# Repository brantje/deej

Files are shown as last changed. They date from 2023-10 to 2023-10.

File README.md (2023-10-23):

# deej

deej is an **open-source hardware volume mixer** for Windows and Linux PCs. It lets you use real-life sliders (like a DJ!) to **seamlessly control the volumes of different apps** (such as your music player, the game you're playing and your voice chat session) without having to stop what you're doing.

**Join the [deej Discord server](https://discord.gg/nf88NJu) if you need help or have any questions!**



> **_New:_** [work-in-progress deej FAQ](./docs/faq/faq.md)!

deej consists of a [lightweight desktop client](#features) written in Go, and an Arduino-based hardware setup that's simple and cheap to build. [**Check out some versions built by members of our community!**](./community.md)

**[Download the latest release](https://github.com/omriharel/deej/releases/latest) | [Video demonstration](https://youtu.be/VoByJ4USMr8) | [Build video by Tech Always](https://youtu.be/x2yXbFiiAeI)**

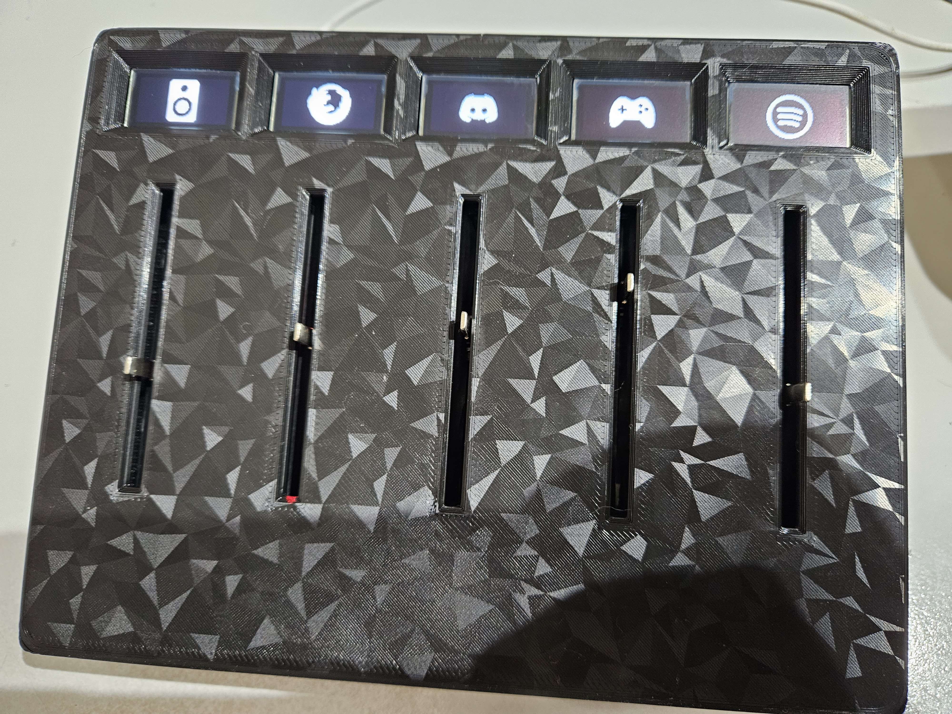
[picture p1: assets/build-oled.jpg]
deej


## BOM

- 1x Arduino Pro Micro
- 1x TCA9548A I2C Multiplexer
- 5x Sliding Potentiometer with Board (10kΩ) [example](assets/slider.jpg)
- 5x 0.96 inch OLED Display 128\*64 pixels (27mm x 27mm) (Cheap ones on eg AliExpress)

## Table of contents

- [Features](#features)
- [How it works](#how-it-works)
  - [Hardware](#hardware)
    - [Schematic](#schematic)
  - [Software](#software)
- [Slider mapping (configuration)](#slider-mapping-configuration)
- [Build your own!](#build-your-own)
  - [FAQ](#faq)
  - [Build video](#build-video)
  - [Bill of Materials](#bill-of-materials)
  - [Thingiverse collection](#thingiverse-collection)
  - [Build procedure](#build-procedure)
- [How to run](#how-to-run)
  - [Requirements](#requirements)
  - [Download and installation](#download-and-installation)
  - [Building from source](#building-from-source)
- [Community](#community)
- [License](#license)

## Features

deej is written in Go and [distributed](https://github.com/omriharel/deej/releases/latest) as a portable (no installer needed) executable.

- Bind apps to different sliders
  - Bind multiple apps per slider (i.e. one slider for all your games)
  - Bind the master channel
  - Bind "system sounds" (on Windows)
  - Bind specific audio devices by name (on Windows)
  - Bind currently active app (on Windows)
  - Bind all other unassigned apps
- Control your microphone's input level
- Lightweight desktop client, consuming around 10MB of memory
- Runs from your system tray
- Helpful notifications to let you know if something isn't working

> **Looking for the older Python version?** It's no longer maintained, but you can always find it in the [`legacy-python` branch](https://github.com/omriharel/deej/tree/legacy-python).

## How it works

### Hardware

- The sliders are connected to 5 (or as many as you like) analog pins on an Arduino Nano/Uno board. They're powered from the board's 5V output (see schematic)
- The board connects via a USB cable to the PC

#### Schematic

Hardware schematic

### Software

- The code running on the Arduino board is a [C program](./arduino/deej-5-sliders-vanilla/deej-5-sliders-vanilla.ino) constantly writing current slider values over its serial interface
- The PC runs a lightweight [Go client](./pkg/deej/cmd/main.go) in the background. This client reads the serial stream and adjusts app volumes according to the given configuration file

## Slider mapping (configuration)

deej uses a simple YAML-formatted configuration file named [`config.yaml`](./config.yaml), placed alongside the deej executable.

The config file determines which applications (and devices) are mapped to which sliders, and which parameters to use for the connection to the Arduino board, as well as other user preferences.

**This file auto-reloads when its contents are changed, so you can change application mappings on-the-fly without restarting deej.**

It looks like this:

```yaml
slider_mapping:
  0: master
  1: chrome.exe
  2: spotify.exe
  3:
    - pathofexile_x64.exe
    - rocketleague.exe
  4: discord.exe

# set this to true if you want the controls inverted (i.e. top is 0%, bottom is 100%)
invert_sliders: false

# settings for connecting to the arduino board
com_port: COM4
baud_rate: 9600

# adjust the amount of signal noise reduction depending on your hardware quality
# supported values are "low" (excellent hardware), "default" (regular hardware) or "high" (bad, noisy hardware)
noise_reduction: default
```

- `master` is a special option to control the master volume of the system _(uses the default playback device)_
- `mic` is a special option to control your microphone's input level _(uses the default recording device)_
- `deej.unmapped` is a special option to control all apps that aren't bound to any slider ("everything else")
- On Windows, `deej.current` is a special option to control whichever app is currently in focus
- On Windows, you can specify a device's full name, i.e. `Speakers (Realtek High Definition Audio)`, to bind that device's level to a slider. This doesn't conflict with the default `master` and `mic` options, and works for both input and output devices.
  - Be sure to use the full device name, as seen in the menu that comes up when left-clicking the speaker icon in the tray menu
- `system` is a special option on Windows to control the "System sounds" volume in the Windows mixer
- All names are case-**in**sensitive, meaning both `chrome.exe` and `CHROME.exe` will work
- You can create groups of process names (using a list) to either:
  - control more than one app with a single slider
  - choose whichever process in the group that's currently running (i.e. to have one slider control any game you're playing)

## Build your own!

Building deej is very simple. You only need a few relatively cheap parts - it's an excellent starter project (and my first Arduino project, personally). Remember that if you need any help or have a question that's not answered here, you can always [join the deej Discord server](https://discord.gg/nf88NJu).

Build deej for yourself, or as an awesome gift for your gaming buddies!

### FAQ

I've started a highly focused effort of writing a proper FAQ page for deej, covering many basic and advanced topics.

It is still _very much a work-in-progress_, but I'm happy to [share it in its current state](./docs/faq/faq.md) in hopes that it at least covers some questions you might have.

FAQ feedback in our [community Discord](https://discord.gg/nf88NJu) is strongly encouraged :)

### Build video

In case you prefer watching to reading, Charles from the [**Tech Always**](https://www.youtube.com/c/TechAlways) YouTube channel has made [**a fantastic video**](https://youtu.be/x2yXbFiiAeI) that covers the basics of building deej for yourself, including parts, costs, assembly and software. I highly recommend checking it out!

### Bill of Materials

- 1x Arduino Pro Micro
- 1x TCA9548A I2C Multiplexer
- 5x Sliding Potentiometer with Board (10kΩ) [example](assets/slider.jpg)
- 5x 0.96 inch OLED Display 128\*64 pixels (27mm x 27mm) (Cheap ones on eg AliExpress)

- An Arduino Nano, Pro Micro or Uno board
  - I officially recommend using a Nano or a Pro Micro for their smaller form-factor, friendlier USB connectors and more analog pins. Plus they're cheaper
  - You can also use any other development board that has a Serial over USB interface
- A few slider potentiometers, up to your number of free analog pins (the cheaper ones cost around 1-2 USD each, and come with a standard 10K Ohm variable resistor. These _should_ work just fine for this project)
  - **Important:** make sure to get **linear** sliders, not logarithmic ones! Check the product description
  - You can also use circular knobs if you like
- Some wires

That being said, if you do have one, read on...

### Thingiverse collection

With many different 3D-printed designs being added to our [community showcase](./community.md), it felt right to gather all of them in a Thingiverse collection for you to browse. If you have access to a 3D printer, feel free to use one of the designs in your build.

**[Visit our community-created design collection on Thingiverse!](https://thingiverse.com/omriharel/collections/deej)**

> You can also [submit your own](https://discord.gg/nf88NJu) design to be added to the collection. Regardless, if you do upload your design to Thingiverse, _please add a `deej` tag to it so that others can find it more easily_.

### Build procedure

- Connect everything according to the [schematic](#schematic)
- Test with a multimeter to be sure your sliders are hooked up correctly
- Flash the Arduino chip with the sketch in [`arduino\deej-5-sliders-vanilla`](./arduino/deej-5-sliders-vanilla/deej-5-sliders-vanilla.ino)
  - _Important:_ If you have more or less than 5 sliders, you must edit the sketch to match what you have
- After flashing, check the serial monitor. You should see a constant stream of values separated by a pipe (`|`) character, e.g. `0|240|1023|0|483`
  - When you move a slider, its corresponding value should move between 0 and 1023
- Congratulations, you're now ready to run the deej executable!

## How to run

### Requirements

#### Windows

- Windows. That's it

#### Linux

- Install `libgtk-3-dev`, `libappindicator3-dev` and `libwebkit2gtk-4.0-dev` for system tray support. Pre-built Linux binaries aren't currently released, so you'll need to [build from source](#building-from-source). If there's demand for pre-built binaries, please [let me know](https://discord.gg/nf88NJu)!

### Download and installation

- Head over to the [releases page](https://github.com/omriharel/deej/releases) and download the [latest version](https://github.com/omriharel/deej/releases/latest)'s executable and configuration file (`deej.exe` and `config.yaml`)
- Place them in the same directory anywhere on your machine
- (Optional, on Windows) Create a shortcut to `deej.exe` and copy it to `%APPDATA%\Microsoft\Windows\Start Menu\Programs\Startup` to have deej run on boot

### Building from source

If you'd rather not download a compiled executable, or want to extend deej or modify it to your needs, feel free to clone the repository and build it yourself. All you need is a Go 1.14 (or above) environment on your machine. If you go this route, make sure to check out the [developer scripts](./pkg/deej/scripts).

Like other Go packages, you can also use the `go get` tool: `go get -u github.com/omriharel/deej`. Please note that the package code now resides in the `pkg/deej` directory, and needs to be imported from there if used inside another project.

If you need any help with this, please [join our Discord server](https://discord.gg/nf88NJu).

## Community



deej is a relatively new project, but a vibrant and awesome community is rapidly growing around it. Come hang out with us in the [deej Discord server](https://discord.gg/nf88NJu), or check out a whole bunch of cool and creative builds made by our members in the [community showcase](./community.md).

The server is also a great place to ask questions, suggest features or report bugs (but of course, feel free to use GitHub if you prefer).

### Donations

If you love deej and want to show your support for this project, you can do so using the link below. Please don't feel obligated to donate - building the project and telling your friends about it goes a very long way! Thank you very much.



### Contributing

Please see [`docs/CONTRIBUTING.md`](./docs/CONTRIBUTING.md).

## License

deej is released under the [MIT license](./LICENSE).

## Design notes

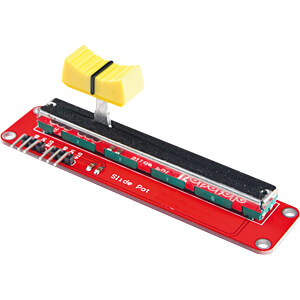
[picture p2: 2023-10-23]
assets/slider.jpg

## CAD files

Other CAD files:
models/fusion 360/parts/OLED 0.96_ V2.0 v1.f3d
models/fusion 360/parts/Slide Potentiometer_92mm v1 (3) v1.f3d

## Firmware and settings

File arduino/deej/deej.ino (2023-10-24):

/*********
# Copyright (C) Sander Brand
# This file is part of Deej <https://github.com/brantje/deej>.
#
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
# You should have received a copy of the GNU General Public License
# along with deej.  If not, see <http://www.gnu.org/licenses/>.
*********/
#include <Wire.h>
#include <Adafruit_GFX.h>
#include <Adafruit_SSD1306.h>
#include <math.h> // For fabs()

#define SCREEN_WIDTH 128
#define SCREEN_HEIGHT 64
#define TCA9548A_ADDRESS 0x70
#define LCD_I2C_ADDRESS 0x3C

#define NOISE_REDUCTION "low"
#define NOISE_REDUCTION_HIGH "high"
#define NOISE_REDUCTION_LOW "low"

const int NUM_SLIDERS = 5;
const int NUM_DISPLAYS = NUM_SLIDERS; // Change if your display amount is different
const int ANALOG_INPUTS[NUM_SLIDERS] = {A0, A1, A2, A6, A3};
const int DISPLAY_SLIDER_MAP[NUM_DISPLAYS] = {0, 1, 4, 3, 2}; // Slider -> Display
const bool INVERT_SLIDERS = false;
int LOOP_COUNTER = 0;
int ANALOG_SLIDER_VALUES[NUM_SLIDERS];
float DISPLAY_VALUES[NUM_DISPLAYS];

const char START_SERIAL_TAG[] = "<<START>>";
const char END_SERIAL_TAG[] = "<<END>>";
boolean isReceiving = false;
int display_idx = 1;
int x = 0, y = 0;

const int BUFFER_SIZE = 128;
char buffer[BUFFER_SIZE];
int bufferIndex = 0;
enum State
{
  WAITING_FOR_START,
  RECEIVING_DATA,
  WAITING_FOR_END
};
State currentState = WAITING_FOR_START;

bool INITIALIZED = false;

Adafruit_SSD1306 display(SCREEN_WIDTH, SCREEN_HEIGHT, &Wire, -1);

void setup()
{

  for (int i = 0; i < NUM_SLIDERS; i++)
  {
    pinMode(ANALOG_INPUTS[i], INPUT);
    ANALOG_SLIDER_VALUES[i] = getSliderValue(ANALOG_INPUTS[i]);
  }
  Wire.begin();
  for (int i = 0; i < NUM_DISPLAYS; i++)
  {
    DISPLAY_VALUES[i] = 100;
    initializeDisplay(DISPLAY_SLIDER_MAP[i]);
  }
  Serial.begin(9600);
  INITIALIZED = true;
  delay(1000);
}

void loop()
{
  updateSliderValues();
  sendSliderValues(); // Actually send data (all the time)
  recvWithStartEndMarkers();
  // if (INITIALIZED)
  // {
  //   for (int i = 0; i < NUM_DISPLAYS; i++)
  //   {
  //     unsigned long now = millis();
  //     long diff = now - DISPLAY_LAST_CHANGED_TIME[i];
  //     if (diff > 2000 && DISPLAY_LAST_CHANGED_TIME[i] != -1)
  //     {
  //       // showIcon(i, i);
  //     }
  //   }
  // }
  // printSliderValues(); // For debug
  delay(10);
}

void TCA9548A(uint8_t bus)
{
  Wire.beginTransmission(TCA9548A_ADDRESS); // TCA9548A address
  Wire.write(1 << bus);                     // send byte to select bus
  Wire.endTransmission();
}

void initializeDisplay(int display_idx)
{
  TCA9548A(display_idx);
  if (!display.begin(SSD1306_SWITCHCAPVCC, LCD_I2C_ADDRESS))
  {
    Serial.println(F("SSD1306 allocation failed"));
    for (;;)
      ;
  }
  // Clear the buffer
  display.clearDisplay();
}

void recvWithStartEndMarkers()
{
  while (Serial.available())
  {
    char c = Serial.read();
    if (bufferIndex < BUFFER_SIZE - 1)
    {
      buffer[bufferIndex] = c;
      bufferIndex++;
    }
    else
    {
      // Reset buffer if overflowed
      bufferIndex = 0;
      memset(buffer, 0, BUFFER_SIZE);
    }

    switch (currentState)
    {
    case WAITING_FOR_START:

      if (bufferIndex >= 9 && strncmp(buffer + bufferIndex - strlen(START_SERIAL_TAG), START_SERIAL_TAG, strlen(START_SERIAL_TAG)) == 0)
      {
        // showText(0, "Receiving", 2);
        int display_idx = Serial.readStringUntil('|').toInt();
        currentState = RECEIVING_DATA;
        memset(buffer, 0, BUFFER_SIZE); // Clear buffer
        bufferIndex = 0;
        TCA9548A(DISPLAY_SLIDER_MAP[display_idx]);
        // display.clearDisplay();
      }
      break;

    case RECEIVING_DATA:
      if (bufferIndex >= 7 && strncmp(buffer + bufferIndex - strlen(END_SERIAL_TAG), END_SERIAL_TAG, strlen(END_SERIAL_TAG)) == 0)
      {
        display.display();
        currentState = WAITING_FOR_START;
        isReceiving = false;
        memset(buffer, 0, BUFFER_SIZE); // Clear buffer
        bufferIndex = 0;
        // showText(0, "Ok", 2);
        // Serial.println("Image drawn on display");
        x = 0;
        y = 0;
      }
      else
      {
        for (int bit = 7; bit >= 0; bit--)
        {
          int pixelValue = (c & (1 << bit)) ? 1 : 0;
          display.drawPixel(x, y, pixelValue);
          x++;
          if (x >= SCREEN_WIDTH)
          {
            x = 0;
            y++;
          }
        }
      }
      break;
    }
  }
}

void showVolume(int display_idx, int volume)
{
  return;
  TCA9548A(display_idx);
  int16_t x1;
  int16_t y1;
  uint16_t width;
  uint16_t height;

  String vol = String(volume);

  int posTop = 2;

  display.setTextSize(2);
  display.getTextBounds(vol, 0, 0, &x1, &y1, &width, &height);
  int posRight = SCREEN_WIDTH - width;

  display.fillRect(posRight, posTop, width, height, BLACK);

  display.setTextColor(WHITE);
  display.setCursor((SCREEN_WIDTH - width), posTop);
  display.println(vol); // text to display
  display.display();
}

int getSliderValue(int input)
{
  int value = analogRead(input);
  if (INVERT_SLIDERS)
  {
    value = map(value, 0, 1023, 1023, 0);
  }
  return value;
}

void updateSliderValues()
{
  for (int i = 0; i < NUM_SLIDERS; i++)
  {
    int value = getSliderValue(ANALOG_INPUTS[i]);
    if (INITIALIZED)
    {
      int normalizedOldValue = ANALOG_SLIDER_VALUES[i];
      float normalizedNewValue = map(value, 0, 1020, 0, 100);
      if (significantlyDifferent(DISPLAY_VALUES[i], normalizedNewValue, NOISE_REDUCTION))
      {
        showVolume(DISPLAY_SLIDER_MAP[i], normalizedNewValue);
        DISPLAY_VALUES[i] = normalizedNewValue;
      }
    }
    ANALOG_SLIDER_VALUES[i] = value;
  }
}

bool almostEquals(float a, float b)
{
  return fabs(a - b) < 0.5; // Using a small threshold to determine equality
}

bool significantlyDifferent(float oldVal, float newVal, const char *noiseReductionLevel)
{
  float significantDifferenceThreshold;

  if (strcmp(noiseReductionLevel, NOISE_REDUCTION_HIGH) == 0)
  {
    significantDifferenceThreshold = 3.5;
  }
  else if (strcmp(noiseReductionLevel, NOISE_REDUCTION_LOW) == 0)
  {
    significantDifferenceThreshold = 1.5;
  }
  else
  {
    significantDifferenceThreshold = 2.5;
  }

  if (fabs(oldVal - newVal) >= significantDifferenceThreshold)
  {
    return true;
  }

  // Special behavior is needed around the edges of 0.0 and 1.0
  if ((almostEquals(newVal, 100) && oldVal != 100) || (almostEquals(newVal, 0.0) && oldVal != 0))
  {
    return true;
  }

  // Values are close enough to not warrant any action
  return false;
}

void sendSliderValues()
{
  String builtString = String("");

  for (int i = 0; i < NUM_SLIDERS; i++)
  {
    builtString += String((int)ANALOG_SLIDER_VALUES[i]);

    if (i < NUM_SLIDERS - 1)
    {
      builtString += String("|");
    }
  }

  Serial.println(builtString);
}

void printSliderValues()
{
  for (int i = 0; i < NUM_SLIDERS; i++)
  {
    String printedString = String("Slider #") + String(i + 1) + String(": ") + String(ANALOG_SLIDER_VALUES[i]) + String(" mV");
    Serial.write(printedString.c_str());

    if (i < NUM_SLIDERS - 1)
    {
      Serial.write(" | ");
    }
    else
    {
      Serial.write("\n");
    }
  }
}

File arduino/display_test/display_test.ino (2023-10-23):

/*********
# Copyright (C) Sander Brand
# This file is part of Deej <https://github.com/brantje/deej>.
#
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
# You should have received a copy of the GNU General Public License
# along with deej.  If not, see <http://www.gnu.org/licenses/>.
*********/

#include <Wire.h>
#include <Adafruit_GFX.h>
#include <Adafruit_SSD1306.h>

#define SCREEN_WIDTH 128
#define SCREEN_HEIGHT 64

Adafruit_SSD1306 display(SCREEN_WIDTH, SCREEN_HEIGHT, &Wire, -1);
// '0', 128x64px
const unsigned char icon_0[] PROGMEM = {
    0x00, 0x00, 0x00, 0x00, 0x00, 0x00, 0x00, 0x00, 0x00, 0x00, 0x00, 0x00, 0x00, 0x00, 0x00, 0x00,
    0x00, 0x00, 0x00, 0x00, 0x00, 0x00, 0x00, 0x00, 0x00, 0x00, 0x00, 0x00, 0x00, 0x00, 0x00, 0x00,
    0x00, 0x00, 0x00, 0x00, 0x00, 0x00, 0x00, 0x00, 0x00, 0x00, 0x00, 0x00, 0x00, 0x00, 0x00, 0x00,
    0x00, 0x00, 0x00, 0x00, 0x00, 0x01, 0xff, 0xff, 0xff, 0xff, 0x80, 0x00, 0x00, 0x00, 0x00, 0x00,
    0x00, 0x00, 0x00, 0x00, 0x00, 0x03, 0xff, 0xff, 0xff, 0xff, 0xc0, 0x00, 0x00, 0x00, 0x00, 0x00,
    0x00, 0x00, 0x00, 0x00, 0x00, 0x07, 0xff, 0xff, 0xff, 0xff, 0xe0, 0x00, 0x00, 0x00, 0x00, 0x00,
    0x00, 0x00, 0x00, 0x00, 0x00, 0x0f, 0xff, 0xff, 0xff, 0xff, 0xf0, 0x00, 0x00, 0x00, 0x00, 0x00,
    0x00, 0x00, 0x00, 0x00, 0x00, 0x0f, 0xff, 0xff, 0xff, 0xff, 0xf0, 0x00, 0x00, 0x00, 0x00, 0x00,
    0x00, 0x00, 0x00, 0x00, 0x00, 0x0f, 0xff, 0xff, 0xff, 0xff, 0xf0, 0x00, 0x00, 0x00, 0x00, 0x00,
    0x00, 0x00, 0x00, 0x00, 0x00, 0x0f, 0xff, 0xf8, 0x1f, 0xff, 0xf0, 0x00, 0x00, 0x00, 0x00, 0x00,
    0x00, 0x00, 0x00, 0x00, 0x00, 0x0f, 0xff, 0xf0, 0x0f, 0xff, 0xf0, 0x00, 0x00, 0x00, 0x00, 0x00,
    0x00, 0x00, 0x00, 0x00, 0x00, 0x0f, 0xff, 0xe0, 0x07, 0xff, 0xf0, 0x00, 0x00, 0x00, 0x00, 0x00,
    0x00, 0x00, 0x00, 0x00, 0x00, 0x0f, 0xff, 0xe0, 0x07, 0xff, 0xf0, 0x00, 0x00, 0x00, 0x00, 0x00,
    0x00, 0x00, 0x00, 0x00, 0x00, 0x0f, 0xff, 0xc0, 0x03, 0xff, 0xf0, 0x00, 0x00, 0x00, 0x00, 0x00,
    0x00, 0x00, 0x00, 0x00, 0x00, 0x0f, 0xff, 0xc0, 0x03, 0xff, 0xf0, 0x00, 0x00, 0x00, 0x00, 0x00,
    0x00, 0x00, 0x00, 0x00, 0x00, 0x0f, 0xff, 0xc0, 0x03, 0xff, 0xf0, 0x00, 0x00, 0x00, 0x00, 0x00,
    0x00, 0x00, 0x00, 0x00, 0x00, 0x0f, 0xff, 0xe0, 0x07, 0xff, 0xf0, 0x00, 0x00, 0x00, 0x00, 0x00,
    0x00, 0x00, 0x00, 0x00, 0x00, 0x0f, 0xff, 0xe0, 0x07, 0xff, 0xf0, 0x00, 0x00, 0x00, 0x00, 0x00,
    0x00, 0x00, 0x00, 0x00, 0x00, 0x0f, 0xff, 0xf0, 0x0f, 0xff, 0xf0, 0x00, 0x00, 0x00, 0x00, 0x00,
    0x00, 0x00, 0x00, 0x00, 0x00, 0x0f, 0xff, 0xf8, 0x1f, 0xff, 0xf0, 0x00, 0x00, 0x00, 0x00, 0x00,
    0x00, 0x00, 0x00, 0x00, 0x00, 0x0f, 0xff, 0xff, 0xff, 0xff, 0xf0, 0x00, 0x00, 0x00, 0x00, 0x00,
    0x00, 0x00, 0x00, 0x00, 0x00, 0x0f, 0xff, 0xff, 0xff, 0xff, 0xf0, 0x00, 0x00, 0x00, 0x00, 0x00,
    0x00, 0x00, 0x00, 0x00, 0x00, 0x0f, 0xff, 0xff, 0xff, 0xff, 0xf0, 0x00, 0x00, 0x00, 0x00, 0x00,
    0x00, 0x00, 0x00, 0x00, 0x00, 0x0f, 0xff, 0xff, 0xff, 0xff, 0xf0, 0x00, 0x00, 0x00, 0x00, 0x00,
    0x00, 0x00, 0x00, 0x00, 0x00, 0x0f, 0xff, 0xff, 0xff, 0xff, 0xf0, 0x00, 0x00, 0x00, 0x00, 0x00,
    0x00, 0x00, 0x00, 0x00, 0x00, 0x0f, 0xff, 0xff, 0xff, 0xff, 0xf0, 0x00, 0x00, 0x00, 0x00, 0x00,
    0x00, 0x00, 0x00, 0x00, 0x00, 0x0f, 0xff, 0xfc, 0x3f, 0xff, 0xf0, 0x00, 0x00, 0x00, 0x00, 0x00,
    0x00, 0x00, 0x00, 0x00, 0x00, 0x0f, 0xff, 0xc0, 0x03, 0xff, 0xf0, 0x00, 0x00, 0x00, 0x00, 0x00,
    0x00, 0x00, 0x00, 0x00, 0x00, 0x0f, 0xff, 0x00, 0x00, 0xff, 0xf0, 0x00, 0x00, 0x00, 0x00, 0x00,
    0x00, 0x00, 0x00, 0x00, 0x00, 0x0f, 0xfe, 0x00, 0x00, 0x7f, 0xf0, 0x00, 0x00, 0x00, 0x00, 0x00,
    0x00, 0x00, 0x00, 0x00, 0x00, 0x0f, 0xfc, 0x00, 0x00, 0x3f, 0xf0, 0x00, 0x00, 0x00, 0x00, 0x00,
    0x00, 0x00, 0x00, 0x00, 0x00, 0x0f, 0xf8, 0x00, 0x00, 0x1f, 0xf0, 0x00, 0x00, 0x00, 0x00, 0x00,
    0x00, 0x00, 0x00, 0x00, 0x00, 0x0f, 0xf0, 0x03, 0xc0, 0x0f, 0xf0, 0x00, 0x00, 0x00, 0x00, 0x00,
    0x00, 0x00, 0x00, 0x00, 0x00, 0x0f, 0xe0, 0x1f, 0xf8, 0x07, 0xf0, 0x00, 0x00, 0x00, 0x00, 0x00,
    0x00, 0x00, 0x00, 0x00, 0x00, 0x0f, 0xe0, 0x3f, 0xfc, 0x07, 0xf0, 0x00, 0x00, 0x00, 0x00, 0x00,
    0x00, 0x00, 0x00, 0x00, 0x00, 0x0f, 0xc0, 0x7f, 0xfe, 0x03, 0xf0, 0x00, 0x00, 0x00, 0x00, 0x00,
    0x00, 0x00, 0x00, 0x00, 0x00, 0x0f, 0xc0, 0x7f, 0xfe, 0x03, 0xf0, 0x00, 0x00, 0x00, 0x00, 0x00,
    0x00, 0x00, 0x00, 0x00, 0x00, 0x0f, 0xc0, 0xff, 0xff, 0x03, 0xf0, 0x00, 0x00, 0x00, 0x00, 0x00,
    0x00, 0x00, 0x00, 0x00, 0x00, 0x0f, 0xc0, 0xff, 0xff, 0x03, 0xf0, 0x00, 0x00, 0x00, 0x00, 0x00,
    0x00, 0x00, 0x00, 0x00, 0x00, 0x0f, 0xc0, 0xff, 0xff, 0x03, 0xf0, 0x00, 0x00, 0x00, 0x00, 0x00,
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
// '1', 128x64px
const unsigned char icon_1[] PROGMEM = {
    0x00, 0x00, 0x00, 0x00, 0x00, 0x00, 0x00, 0x00, 0x00, 0x00, 0x00, 0x00, 0x00, 0x00, 0x00, 0x00,
    0x00, 0x00, 0x00, 0x00, 0x00, 0x00, 0x00, 0x00, 0x00, 0x00, 0x00, 0x00, 0x00, 0x00, 0x00, 0x00,
    0x00, 0x00, 0x00, 0x00, 0x00, 0x00, 0x00, 0x00, 0x00, 0x00, 0x00, 0x00, 0x00, 0x00, 0x00, 0x00,
    0x00, 0x00, 0x00, 0x00, 0x00, 0x00, 0x00, 0x00, 0x00, 0x00, 0x00, 0x00, 0x00, 0x00, 0x00, 0x00,
    0x00, 0x00, 0x00, 0x00, 0x00, 0x00, 0x00, 0x00, 0x00, 0x00, 0x00, 0x00, 0x00, 0x00, 0x00, 0x00,
    0x00, 0x00, 0x00, 0x00, 0x00, 0x00, 0x00, 0x0f, 0xfc, 0x00, 0x00, 0x00, 0x00, 0x00, 0x00, 0x00,
    0x00, 0x00, 0x00, 0x00, 0x00, 0x00, 0x00, 0x7f, 0xff, 0xc0, 0x00, 0x00, 0x00, 0x00, 0x00, 0x00,
    0x00, 0x00, 0x00, 0x00, 0x00, 0x00, 0x03, 0xff, 0xff, 0xf0, 0x00, 0x00, 0x00, 0x00, 0x00, 0x00,
    0x00, 0x00, 0x00, 0x00, 0x00, 0x00, 0x07, 0xff, 0xff, 0xfc, 0x00, 0x00, 0x00, 0x00, 0x00, 0x00,
    0x00, 0x00, 0x00, 0x00, 0x00, 0x00, 0x1f, 0xf0, 0x01, 0xfe, 0x00, 0x00, 0x00, 0x00, 0x00, 0x00,
    0x00, 0x00, 0x00, 0x00, 0x00, 0x00, 0x3f, 0x80, 0x00, 0x7f, 0x00, 0x00, 0x00, 0x00, 0x00, 0x00,
    0x00, 0x00, 0x00, 0x00, 0x00, 0x30, 0x7e, 0x00, 0x00, 0x1f, 0xc0, 0x00, 0x00, 0x00, 0x00, 0x00,
    0x00, 0x00, 0x00, 0x00, 0x00, 0x70, 0xfc, 0x00, 0x00, 0x3f, 0xf0, 0x00, 0x00, 0x00, 0x00, 0x00,
    0x00, 0x00, 0x00, 0x00, 0x00, 0x79, 0xf9, 0xf0, 0x00, 0x7f, 0xfb, 0x00, 0x00, 0x00, 0x00, 0x00,
    0x00, 0x00, 0x00, 0x00, 0x00, 0xf9, 0xf7, 0xe0, 0x00, 0x1f, 0xff, 0x80, 0x00, 0x00, 0x00, 0x00,
    0x00, 0x00, 0x00, 0x00, 0x00, 0xff, 0xff, 0xc0, 0x00, 0x07, 0xff, 0x80, 0x00, 0x00, 0x00, 0x00,
    0x00, 0x00, 0x00, 0x00, 0x00, 0xff, 0xff, 0x80, 0x00, 0x01, 0xff, 0x80, 0x00, 0x00, 0x00, 0x00,
    0x00, 0x00, 0x00, 0x00, 0x00, 0xff, 0xff, 0x80, 0x00, 0x00, 0xff, 0xc0, 0x00, 0x00, 0x00, 0x00,
    0x00, 0x00, 0x00, 0x00, 0x00, 0xff, 0xff, 0xc0, 0x00, 0x00, 0x7f, 0xc0, 0x00, 0x00, 0x00, 0x00,
    0x00, 0x00, 0x00, 0x00, 0x00, 0xff, 0xff, 0xf0, 0x00, 0x00, 0x3f, 0xc0, 0x00, 0x00, 0x00, 0x00,
    0x00, 0x00, 0x00, 0x00, 0x00, 0xff, 0xff, 0xff, 0x00, 0x00, 0x1f, 0xc0, 0x00, 0x00, 0x00, 0x00,
    0x00, 0x00, 0x00, 0x00, 0x01, 0xff, 0xff, 0xff, 0x00, 0x00, 0x1f, 0xe0, 0x00, 0x00, 0x00, 0x00,
    0x00, 0x00, 0x00, 0x00, 0x03, 0xff, 0xff, 0xff, 0x00, 0x00, 0x3f, 0xe0, 0x00, 0x00, 0x00, 0x00,
    0x00, 0x00, 0x00, 0x00, 0x07, 0xff, 0xff, 0xfe, 0x00, 0x00, 0x3f, 0xf8, 0x00, 0x00, 0x00, 0x00,
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

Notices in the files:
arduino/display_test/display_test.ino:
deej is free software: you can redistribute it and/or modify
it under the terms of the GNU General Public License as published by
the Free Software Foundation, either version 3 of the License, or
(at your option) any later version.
